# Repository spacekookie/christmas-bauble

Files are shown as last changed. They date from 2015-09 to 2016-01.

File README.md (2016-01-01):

# Kookies Christmas Bauble
A jolly christmas decoration on a PCB. Hoo hoo hoo!

It uses a 555 timer and a shift register + two buttons to generate patterns that are then displayed on a ring of simple LED's on the outside. The perfect thing to hang off your christmas tree in the jolly season (I know I'm early...) :)

The design uses SMD components (except for the LED's that are throughhole). The original schematic and layout was done by Ashley Mills (https://github.com/staropram). **The board requires only one layer**! It can thus be made at home (if the apropriate tools for cutting the PCB are present).

Check out my blog article [here](http://spacekookie.de/hardware/jolly-christmas-decoration/) for details :)
The christmas bauble went into production on 17.11.2015. Unfortunately Revision 3.1 got produced, not the updated and much cooler Rev 3.2** :/ Check out the picture belo.wspi

**All the revision 3 boards up to and including Rev 3.2 have a flaw where the XOR gate (U1) will make the functionality useless!**
Do not solder it on. You have to bridge two pins to make it work. Revision 3.3 fixes the issue.

## Pictures

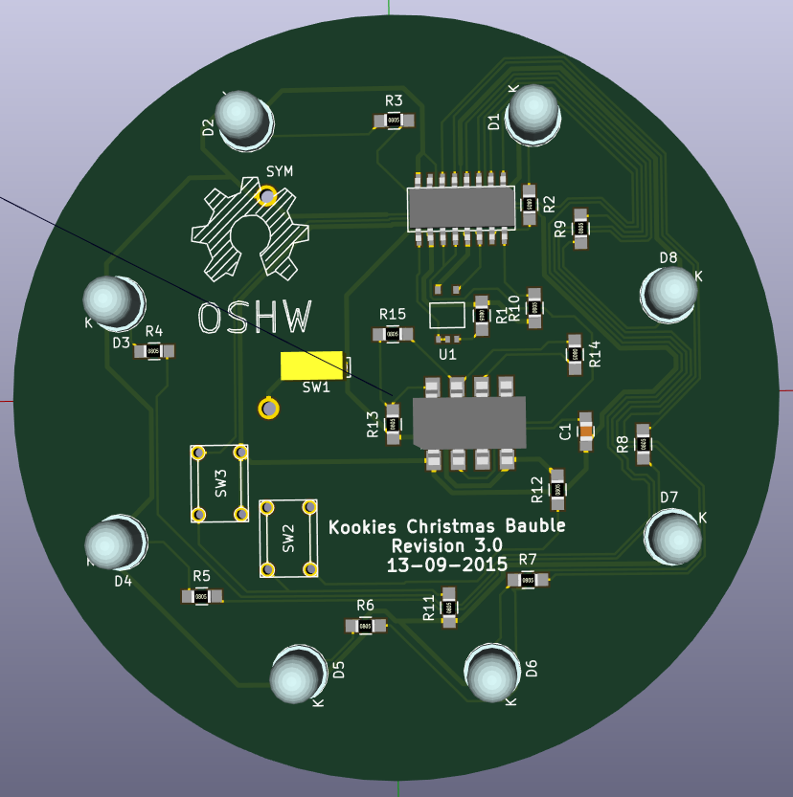
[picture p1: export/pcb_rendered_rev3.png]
PCB Rendered


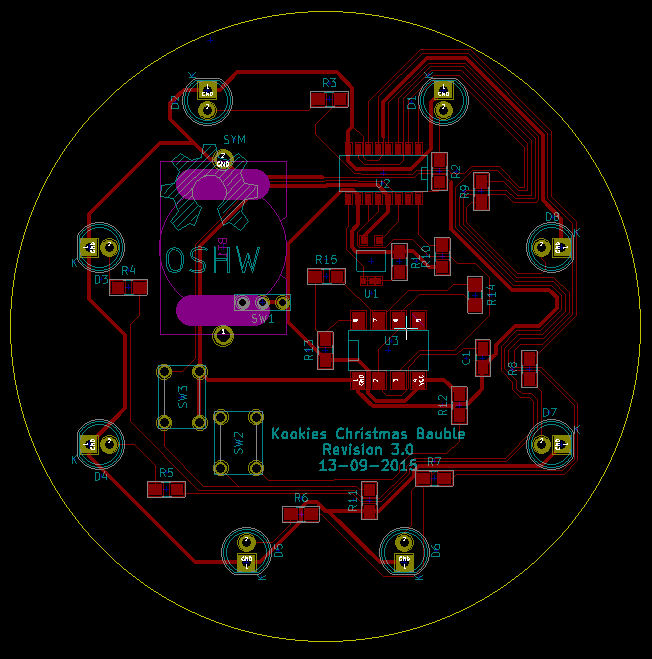
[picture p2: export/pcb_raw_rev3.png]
PCB Raw


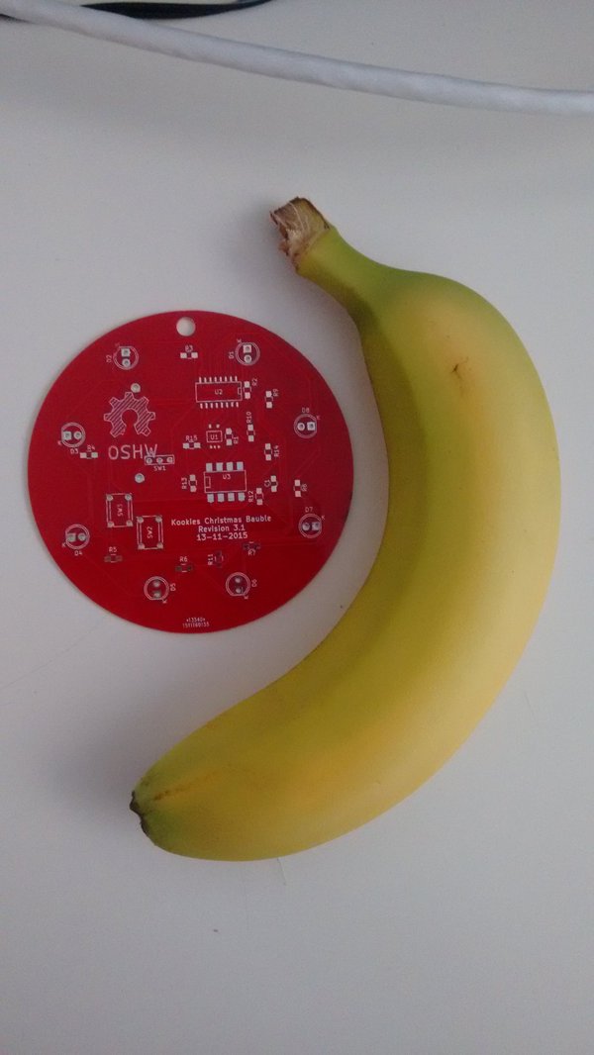
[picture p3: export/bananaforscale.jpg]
PCB Banana For Scale Banana for Scale!


## Partlist

Battery Holder: http://www.mouser.de/ProductDetail/Keystone-Electronics/3012TR/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

Resistors: http://www.mouser.de/Passive-Components/Resistors/SMD-Resistors-Chip-Resistors/_/N-7h7yu?P=1yzmno7Z1yzmotu

595 Shift register: http://www.mouser.de/ProductDetail/Texas-Instruments/SN74HC165DR/?qs=sGAEpiMZZMtYFXwiBRPs00UWwMKcYyCs

555 Timer: http://www.mouser.de/ProductDetail/Texas-Instruments/TLC555CDR/?qs=sGAEpiMZZMuHTYi1bHPYELMHAyKcqQNZ

Capacitor: http://www.mouser.de/ProductDetail/Murata-Electronics/GRM32ER71E226KE15L/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 (you want 22 µF - Not sure if that's included in the Schematic and I'm too lazy to check right now)

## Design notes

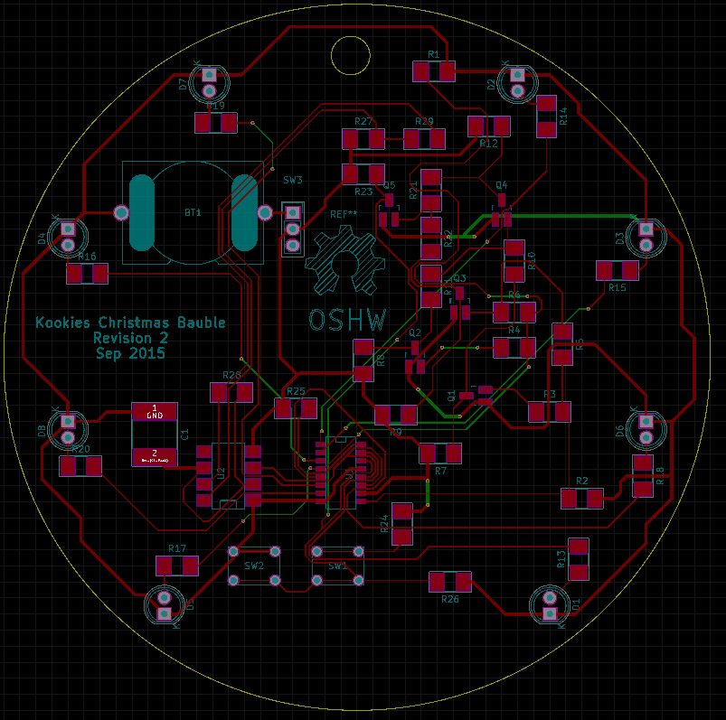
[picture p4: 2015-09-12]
export/pcb_raw.png

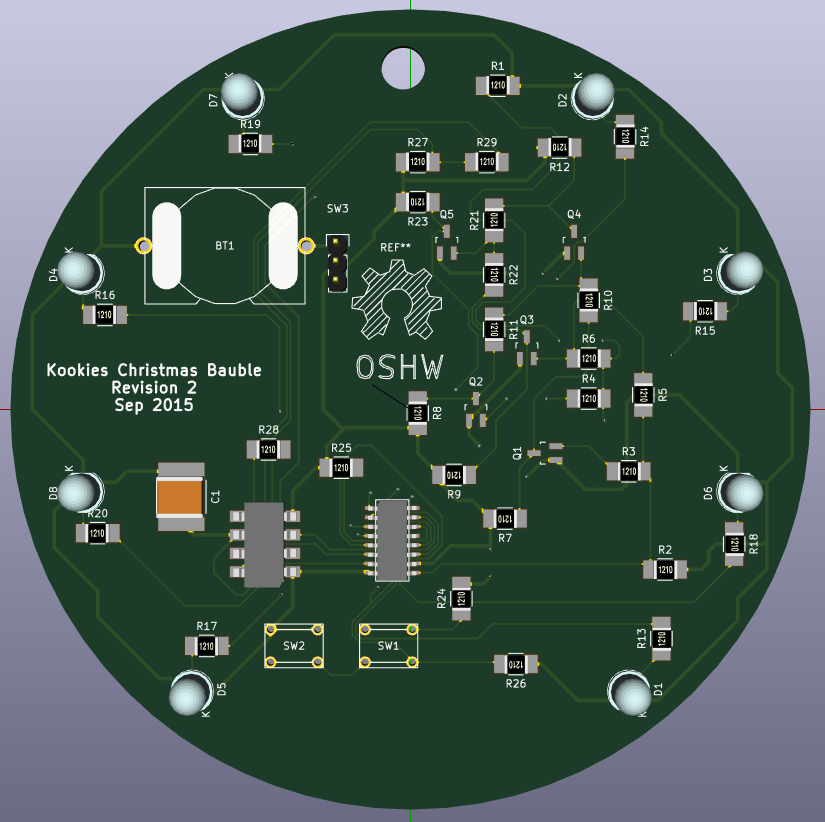
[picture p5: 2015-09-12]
export/pcb_rendered1.png

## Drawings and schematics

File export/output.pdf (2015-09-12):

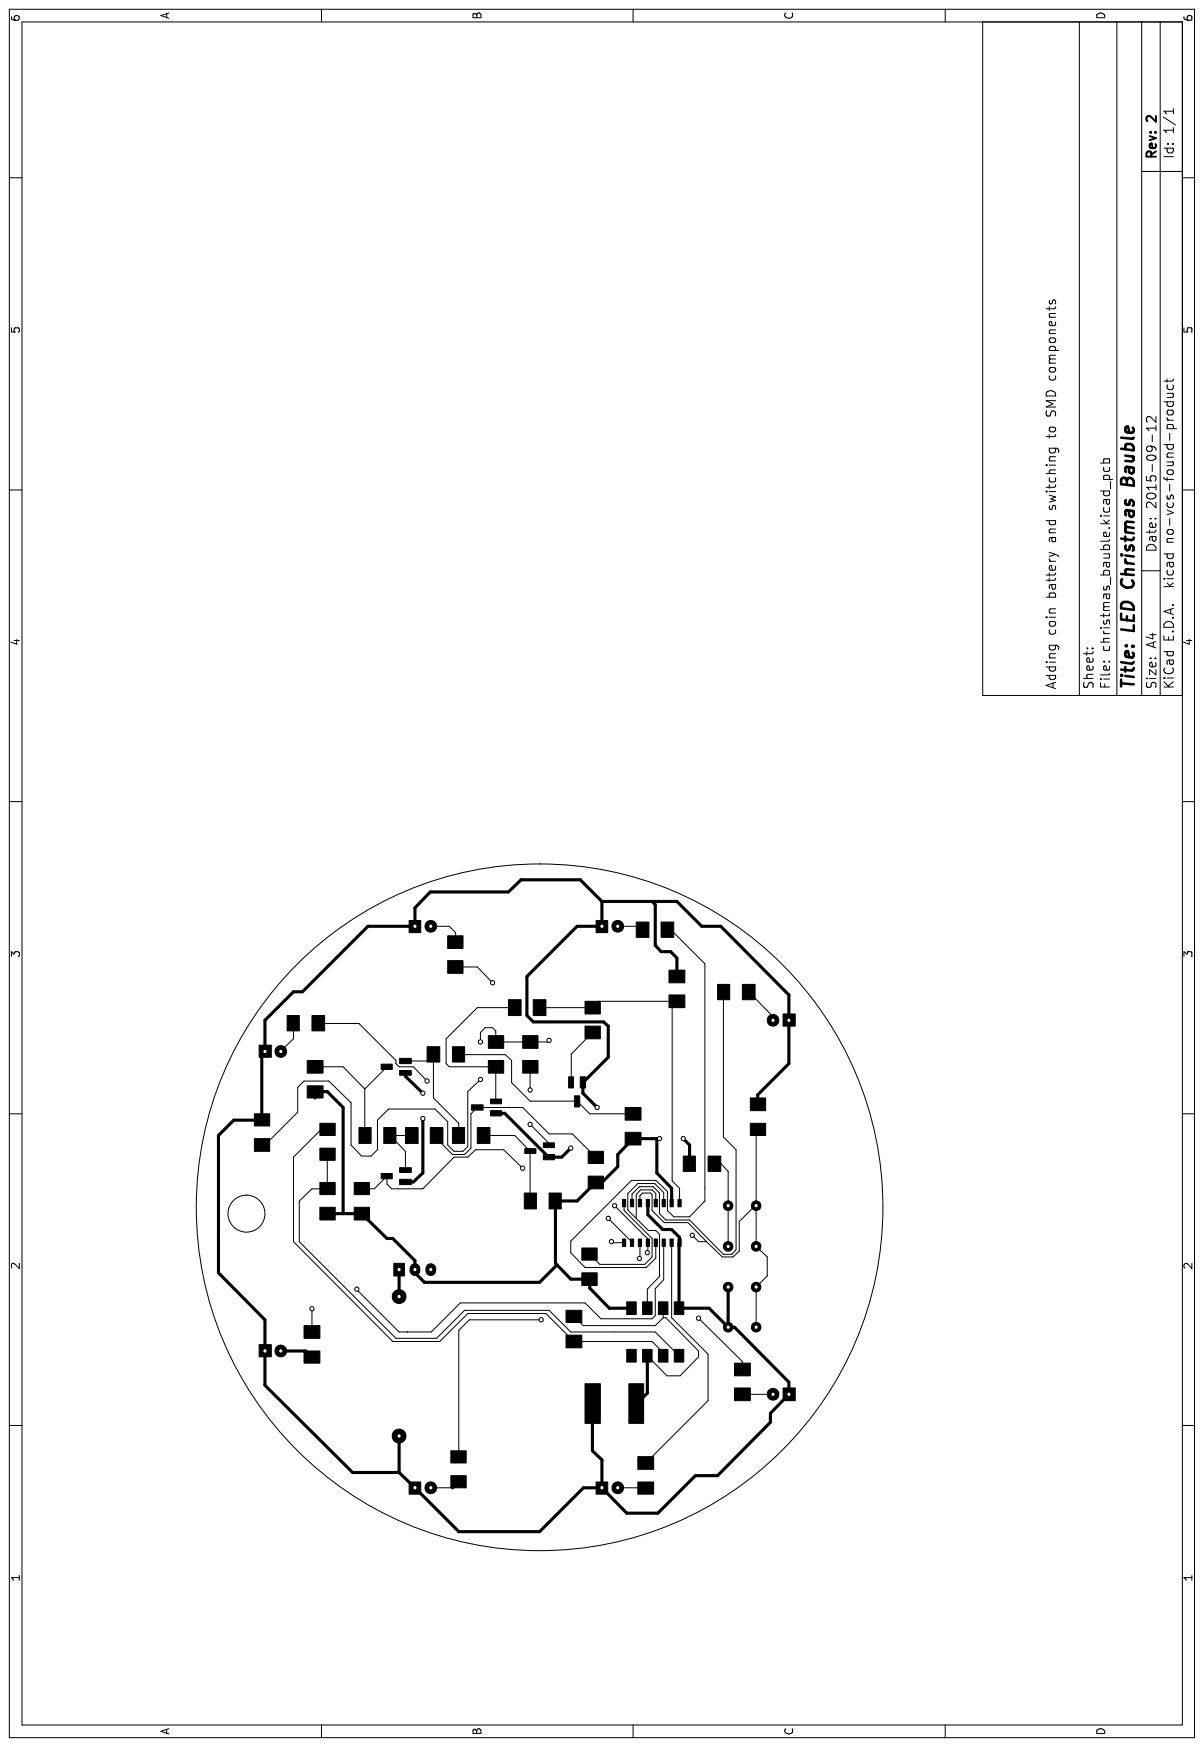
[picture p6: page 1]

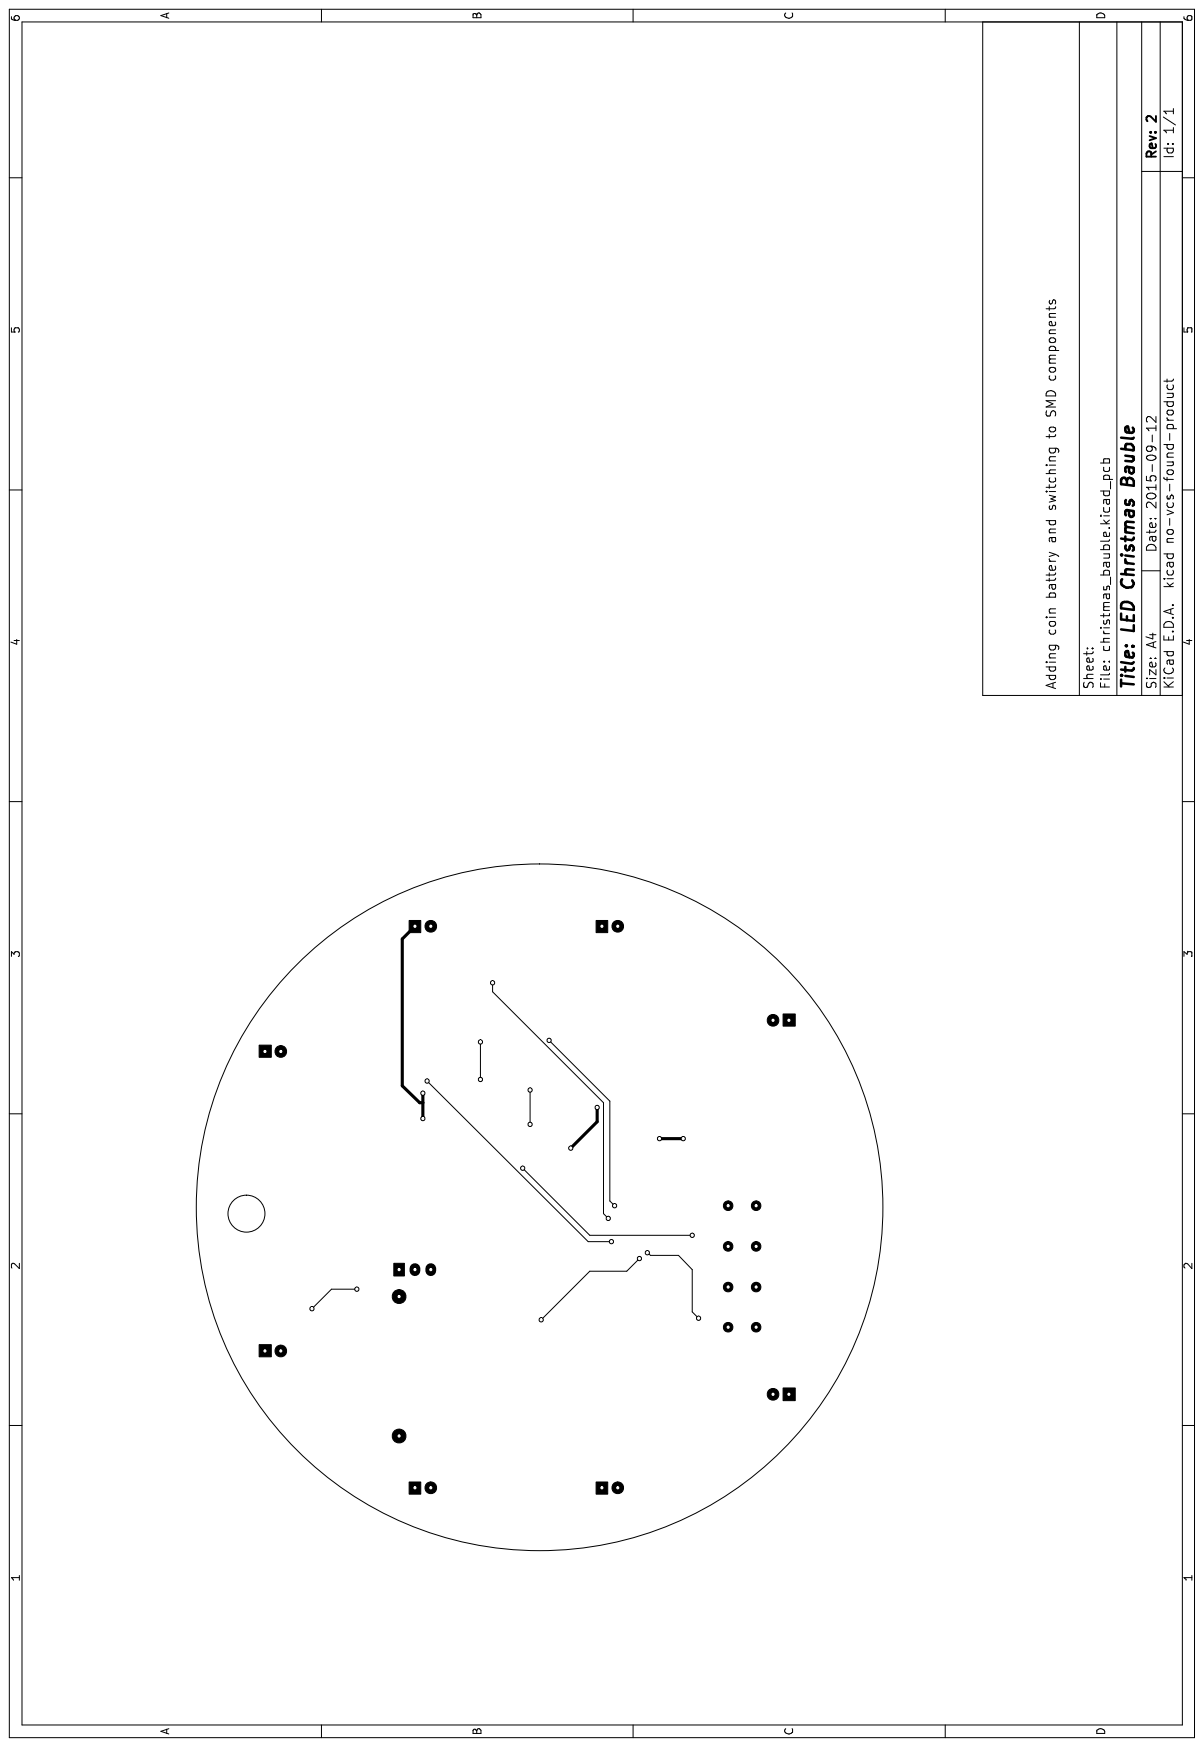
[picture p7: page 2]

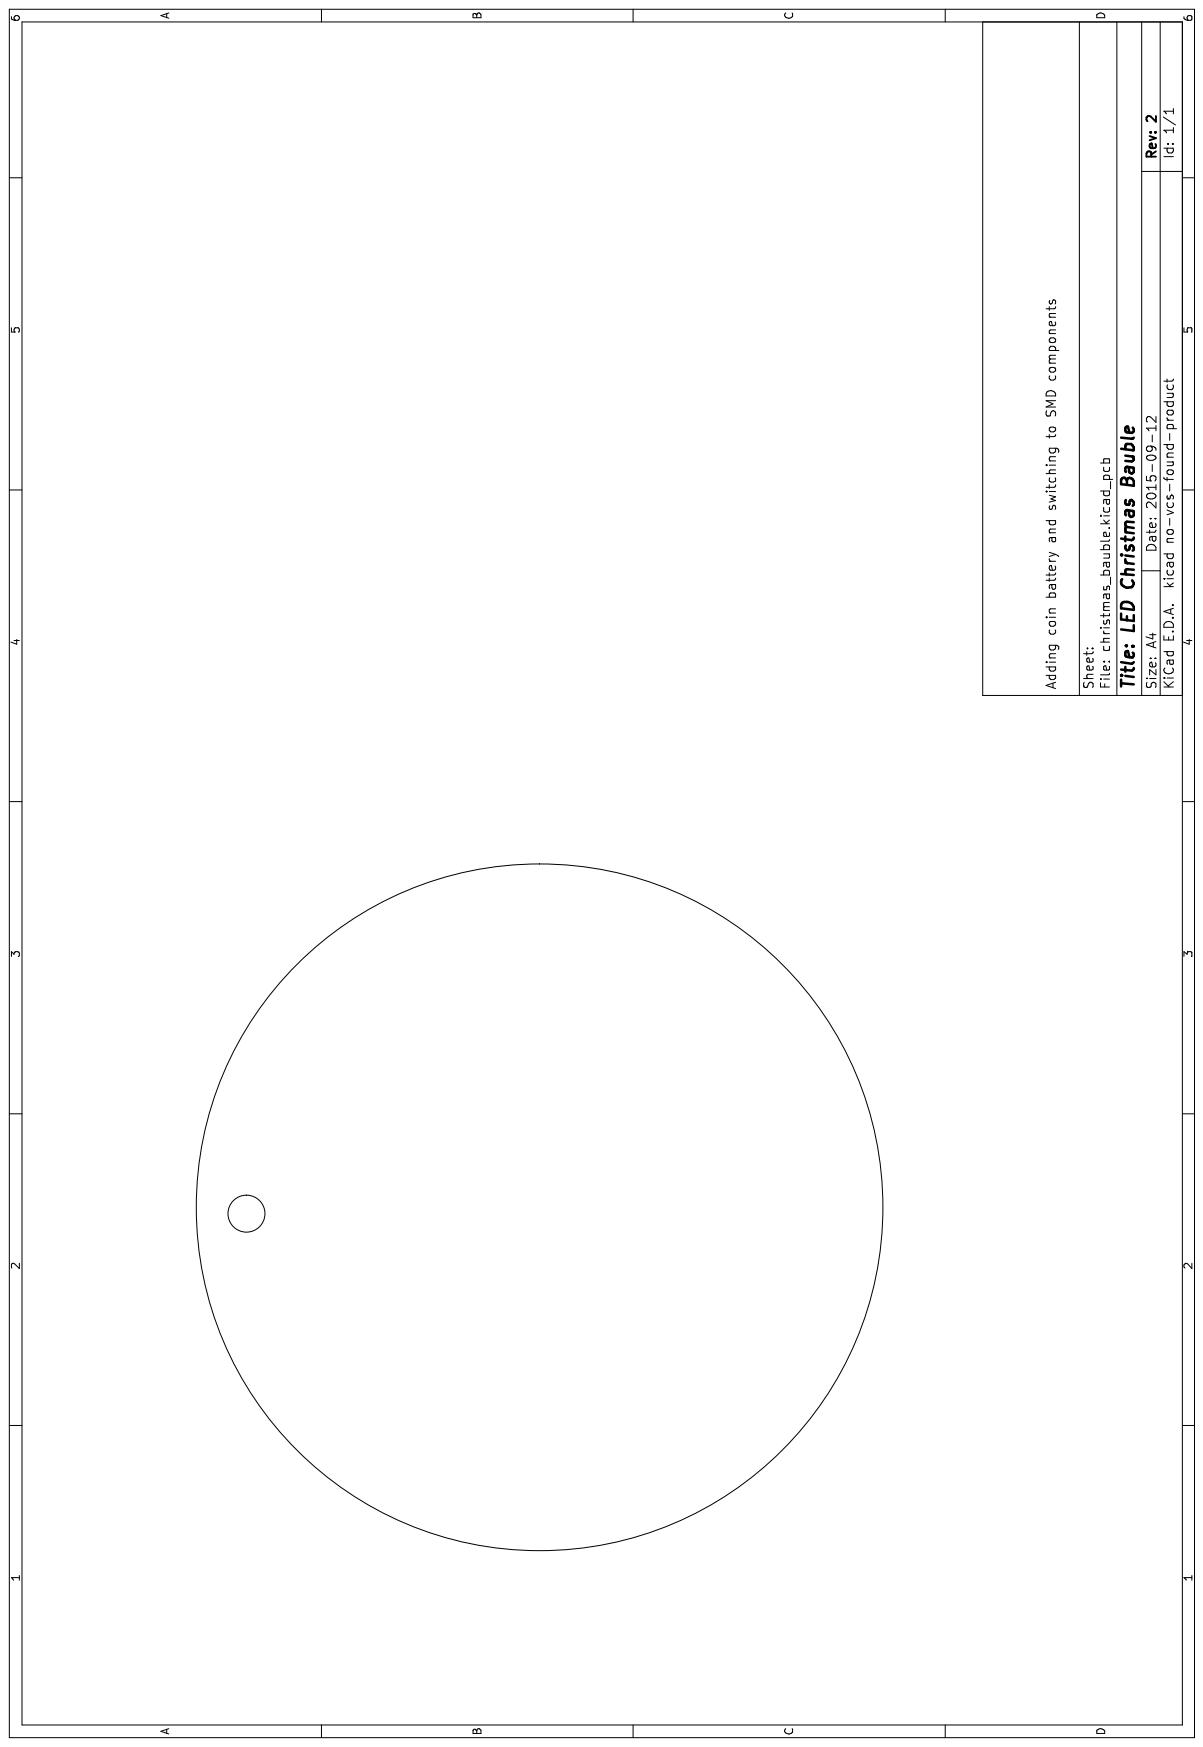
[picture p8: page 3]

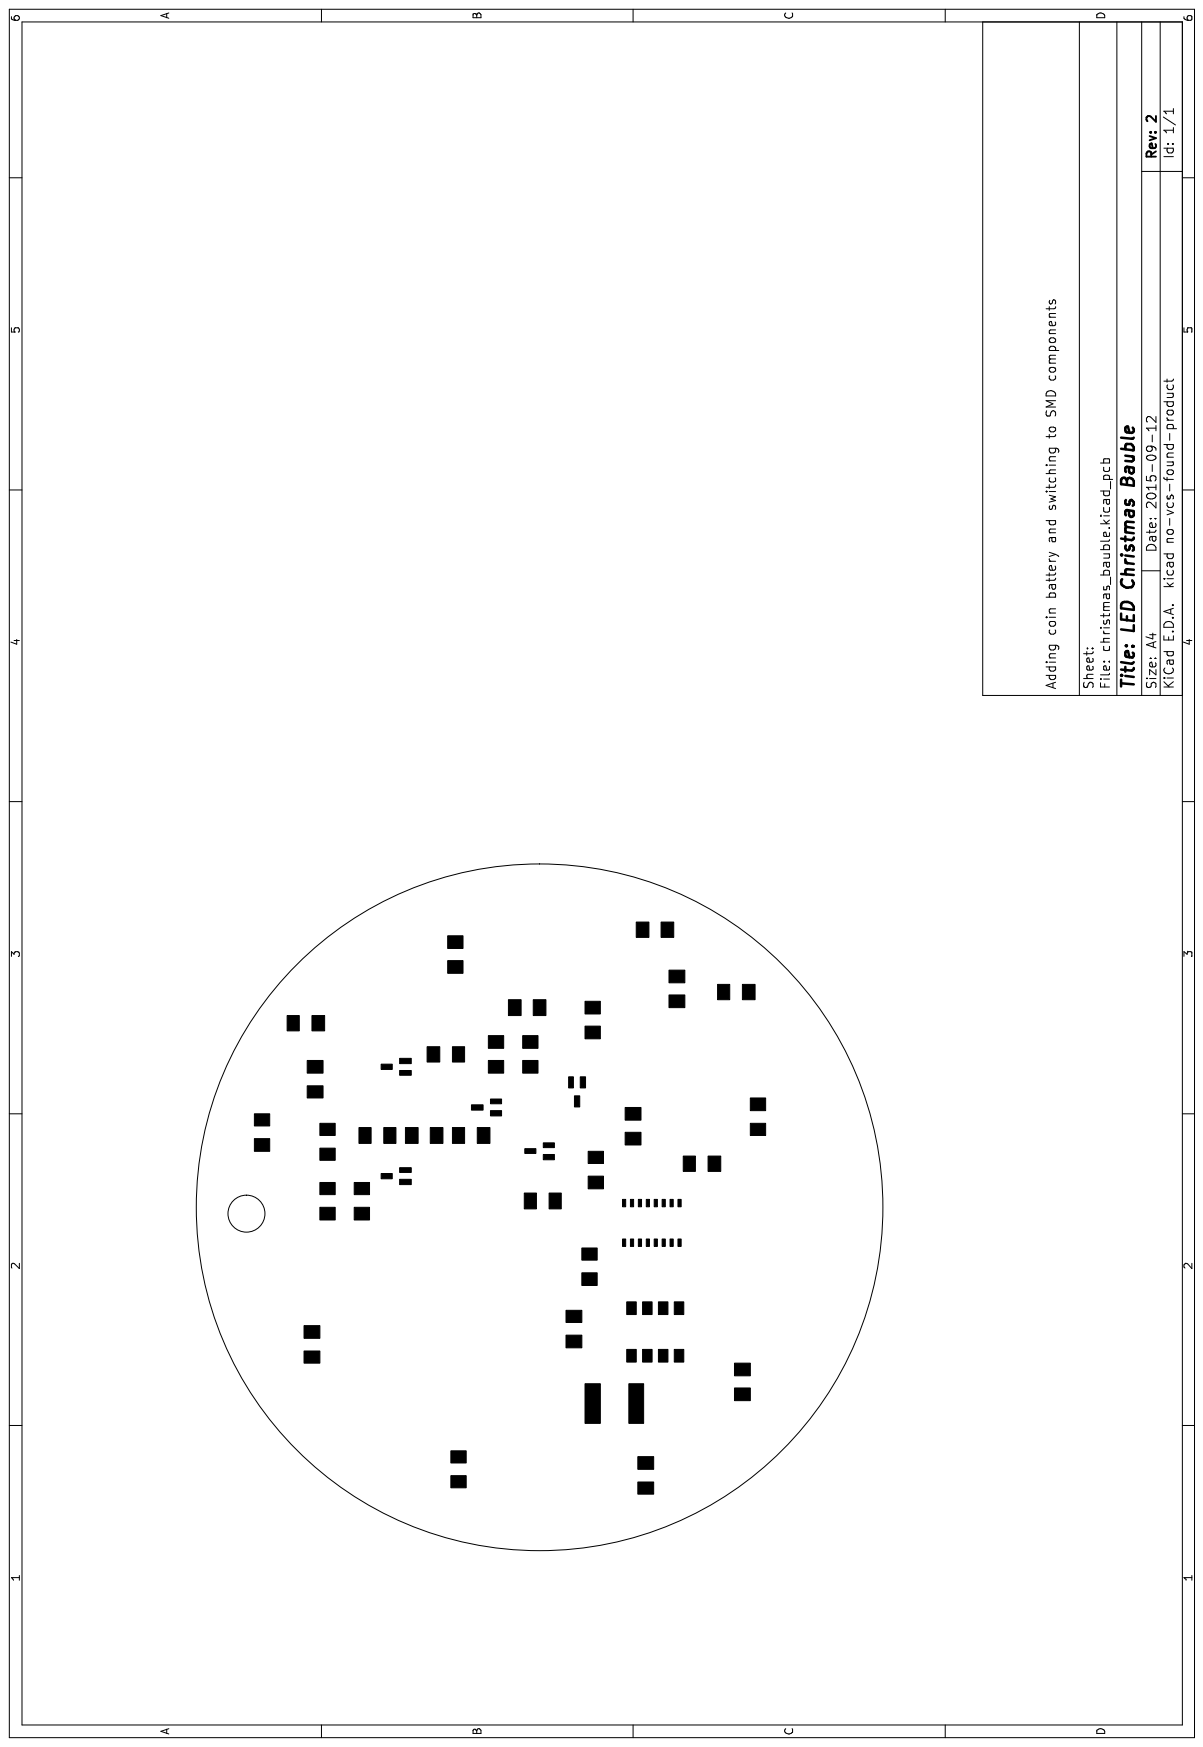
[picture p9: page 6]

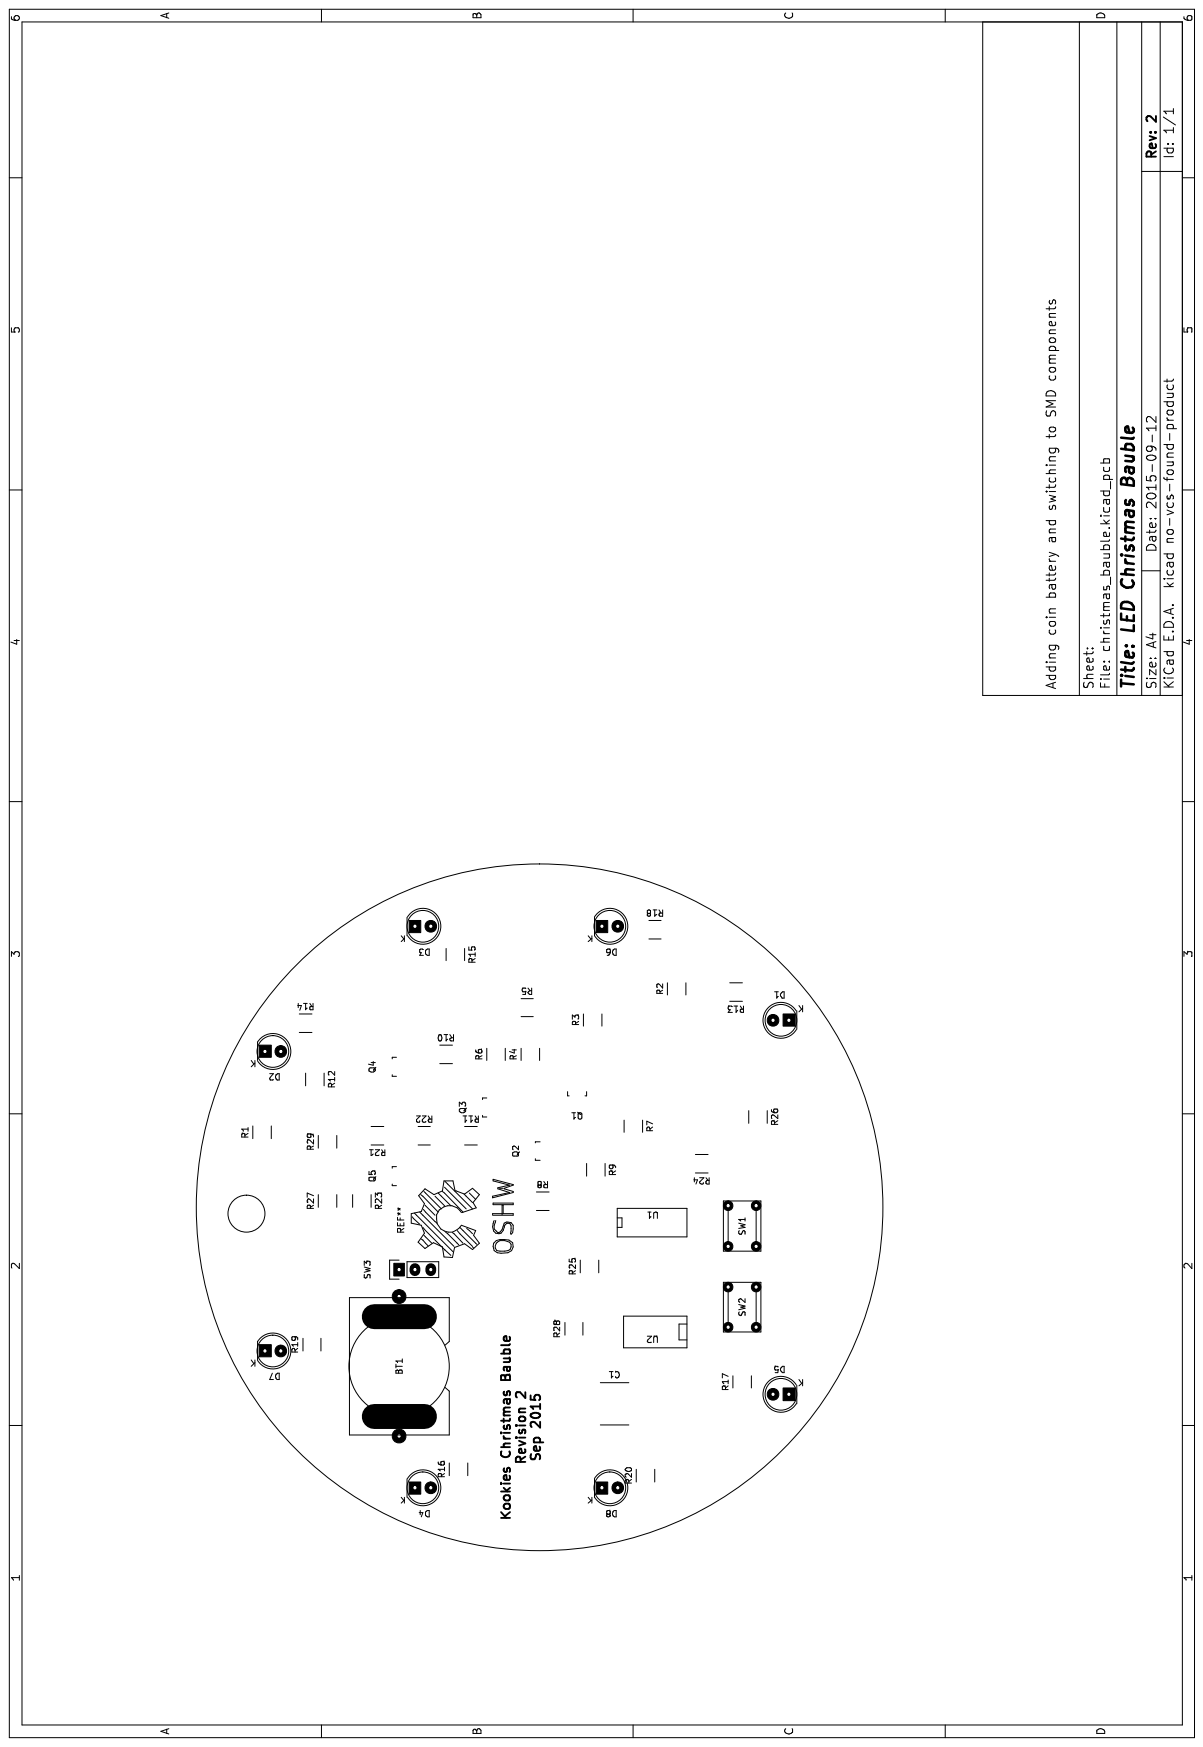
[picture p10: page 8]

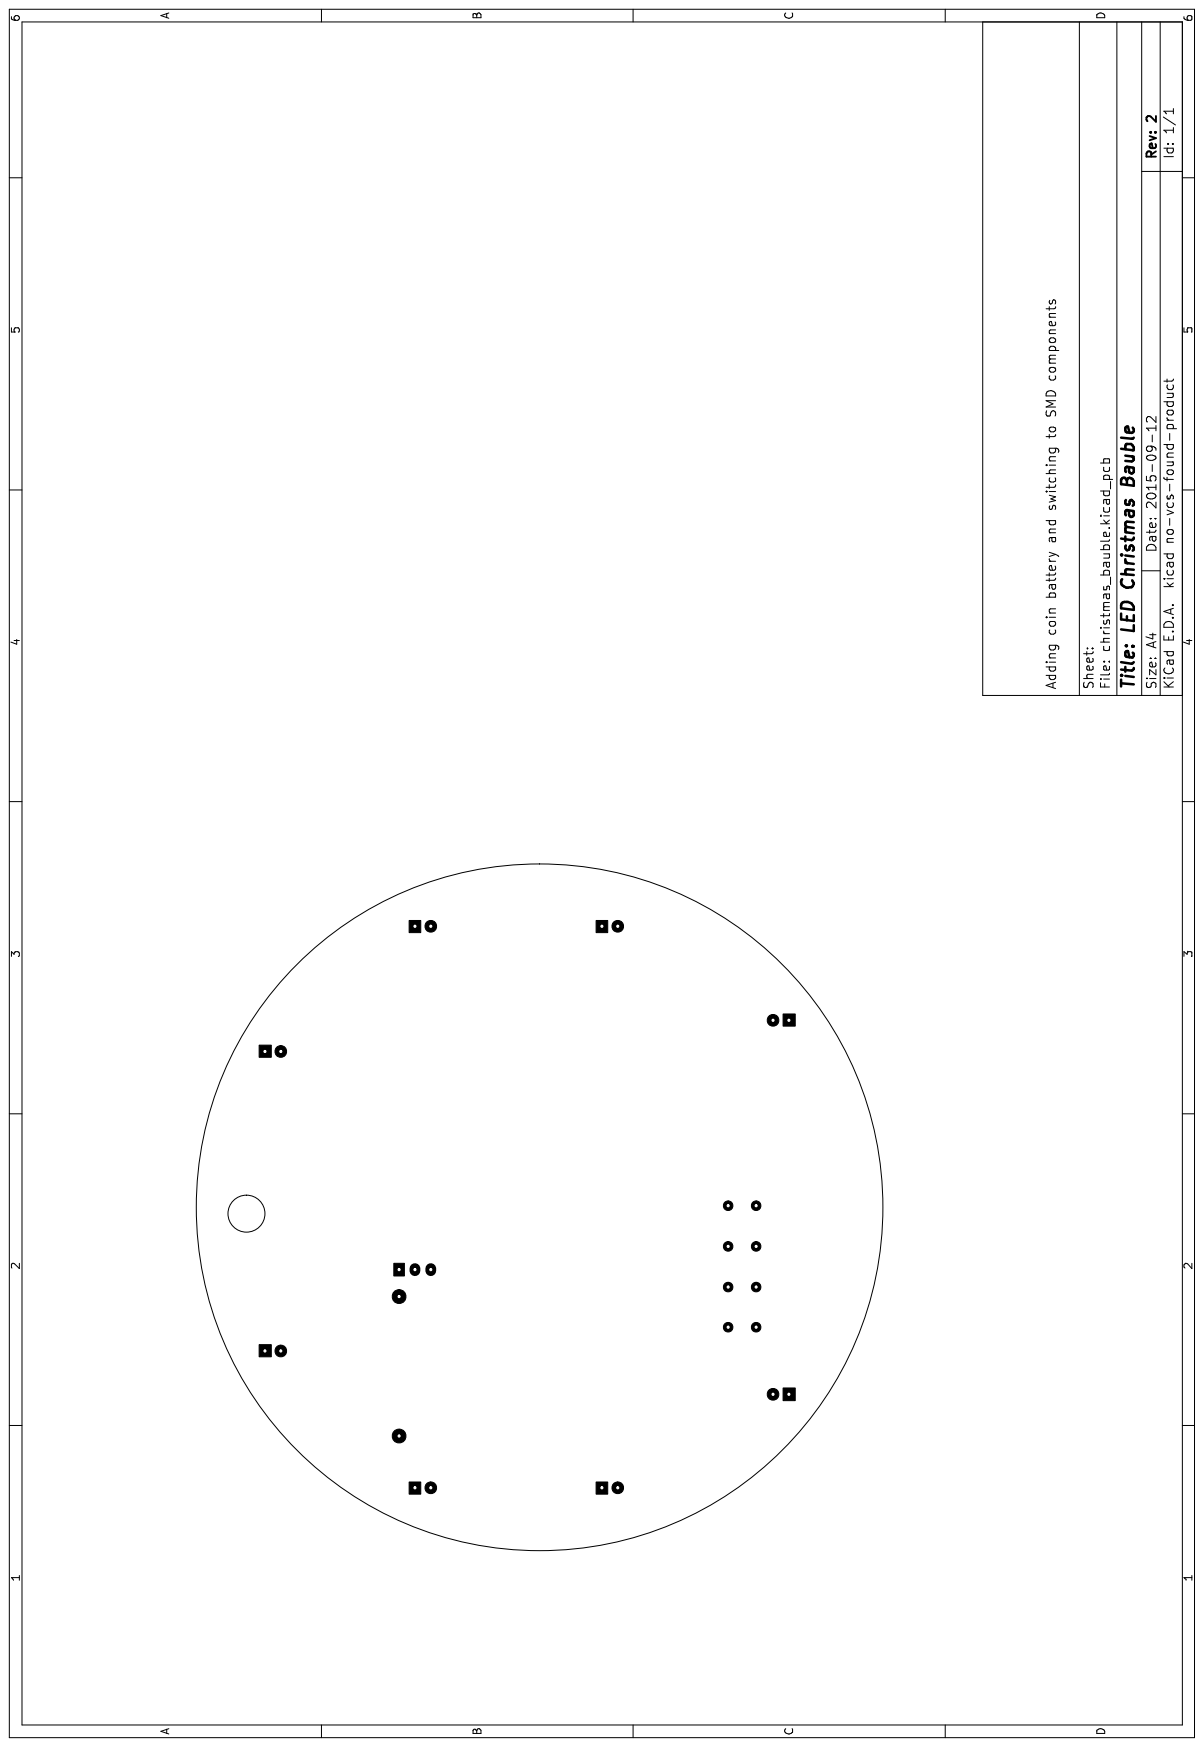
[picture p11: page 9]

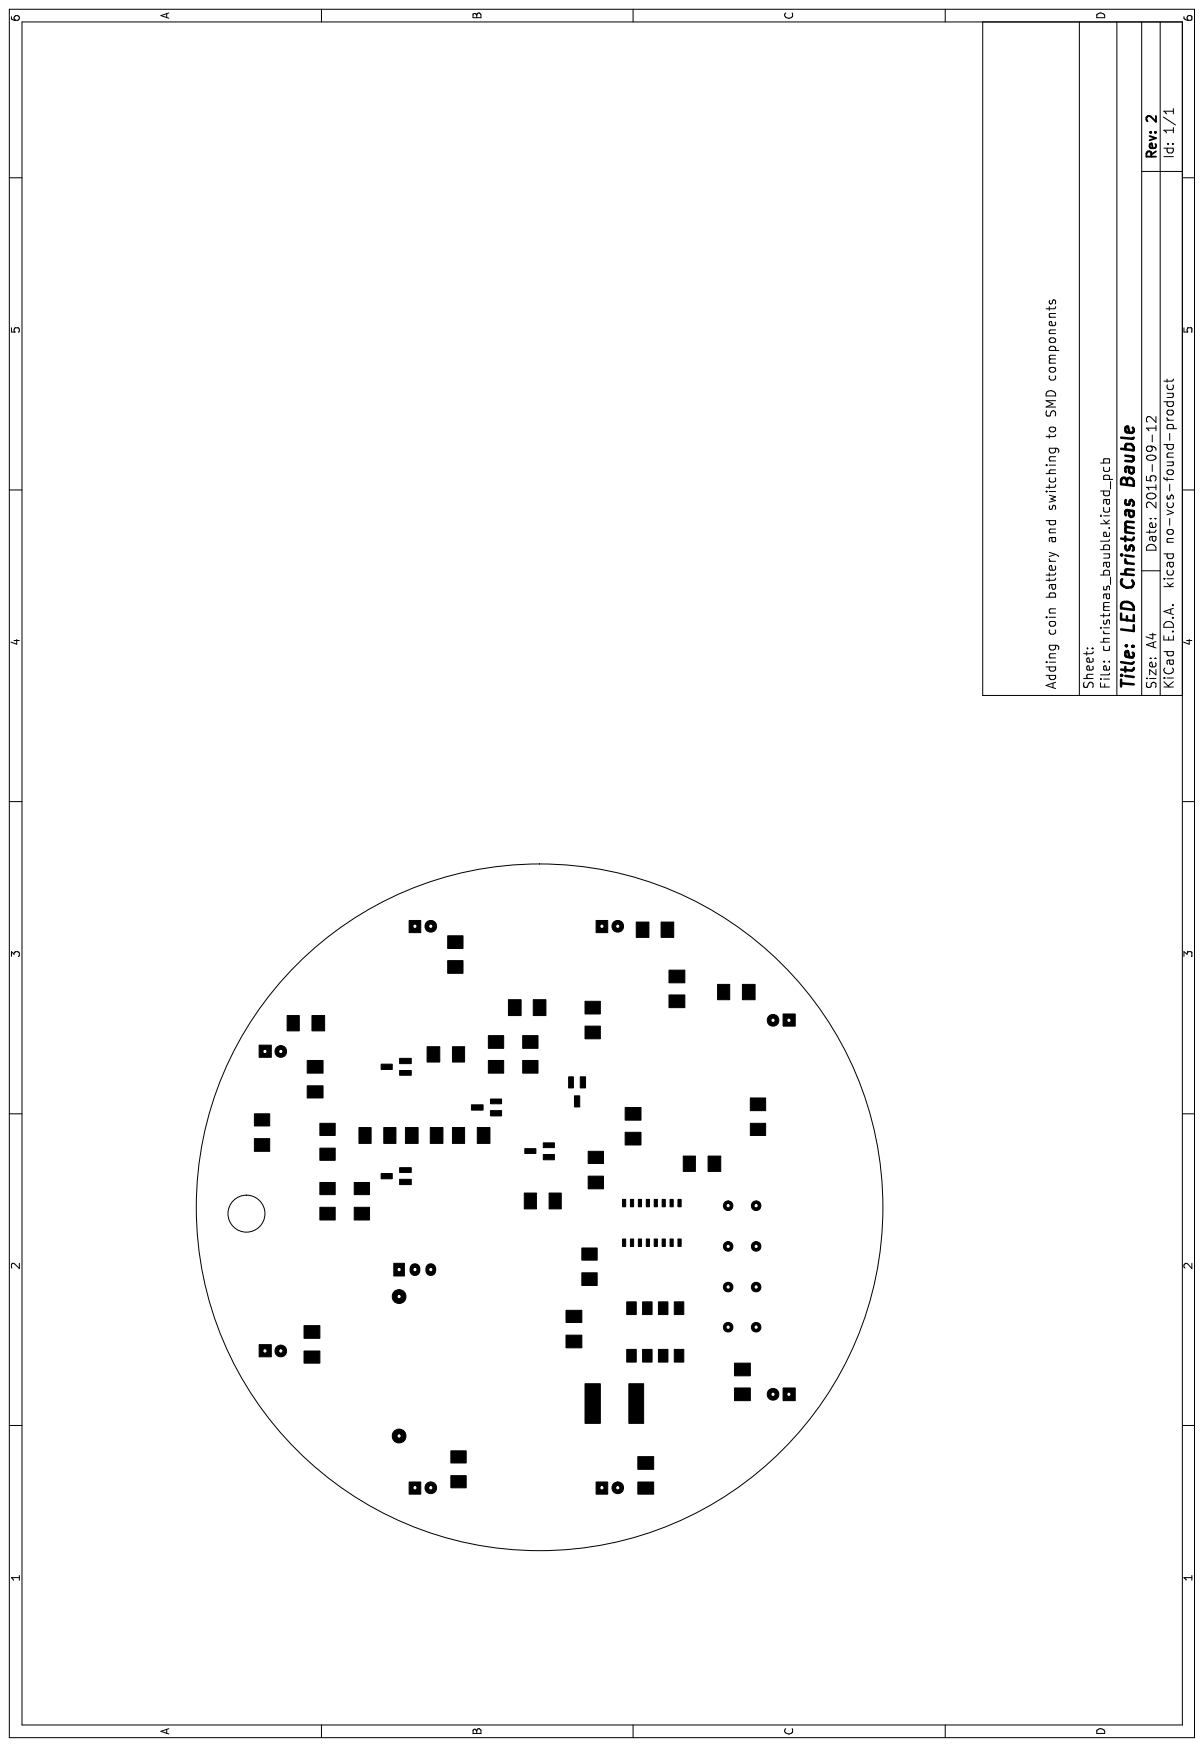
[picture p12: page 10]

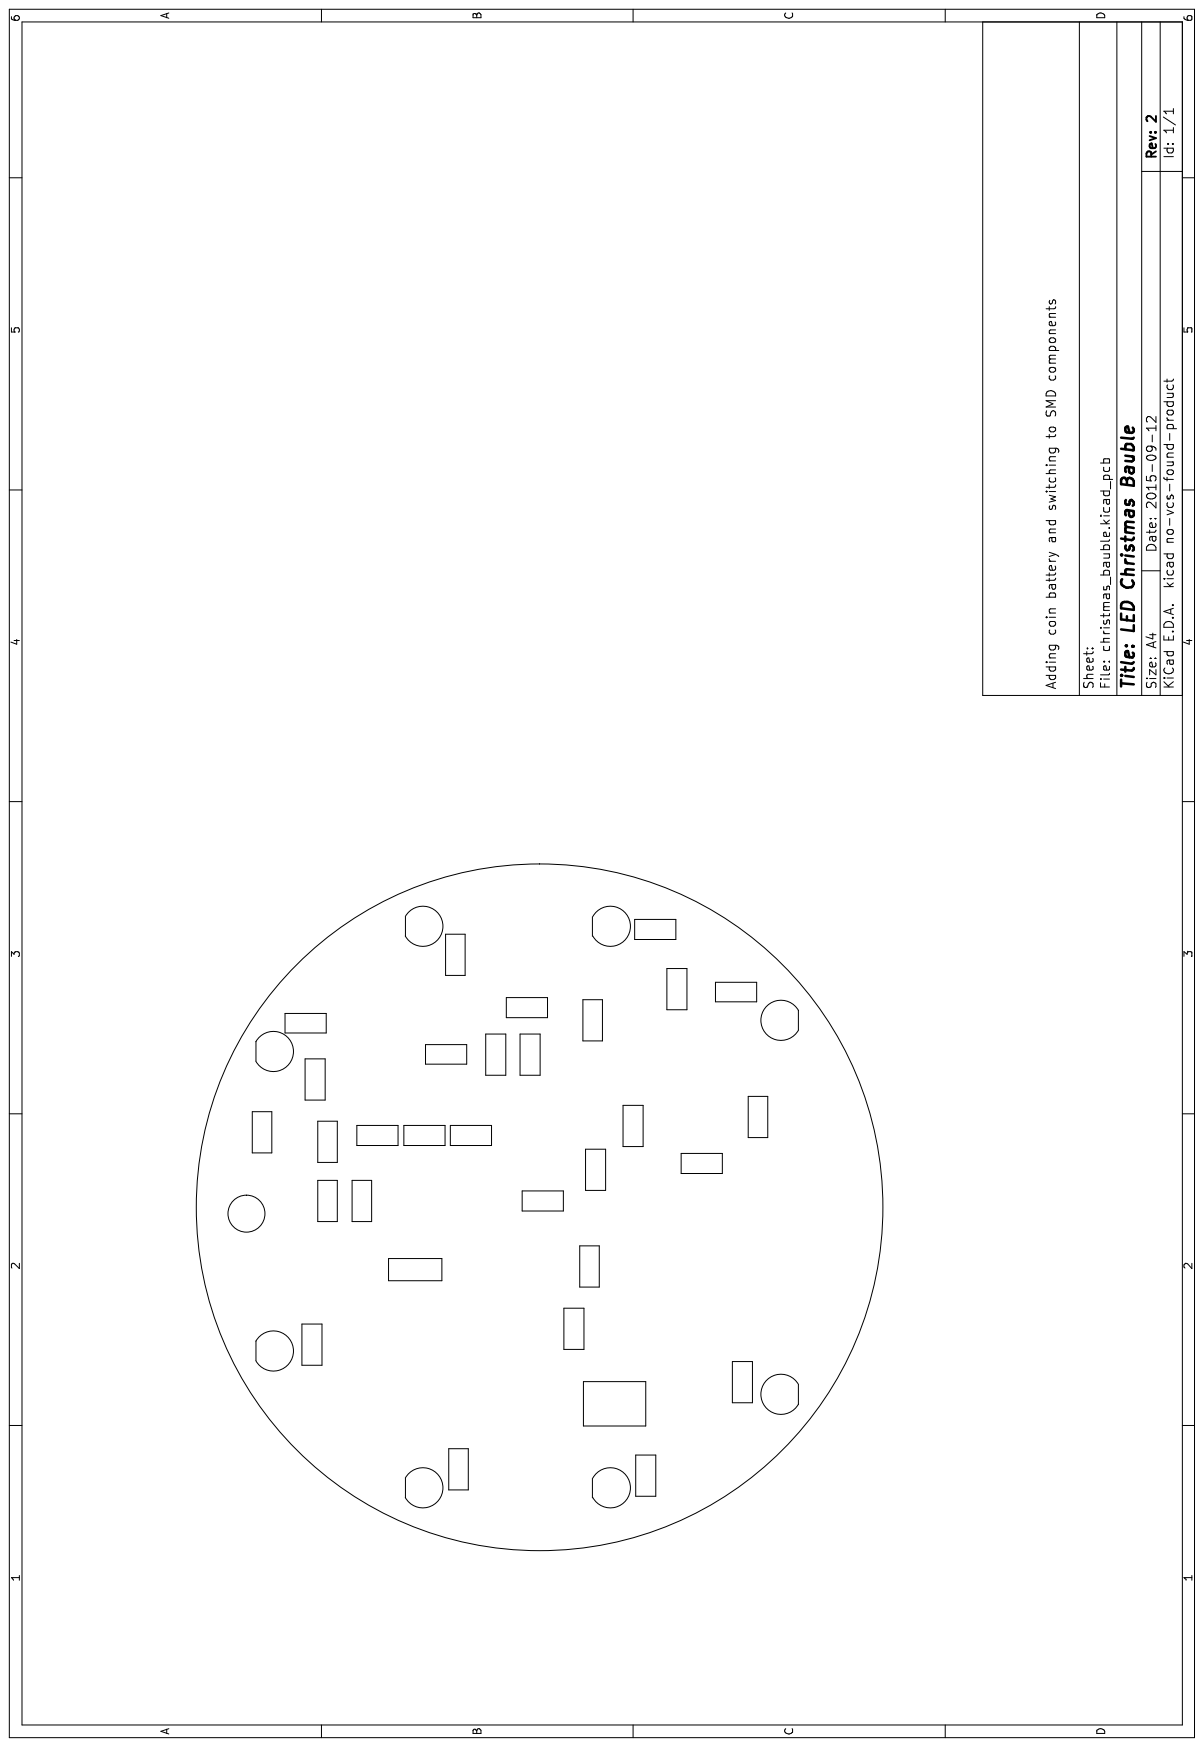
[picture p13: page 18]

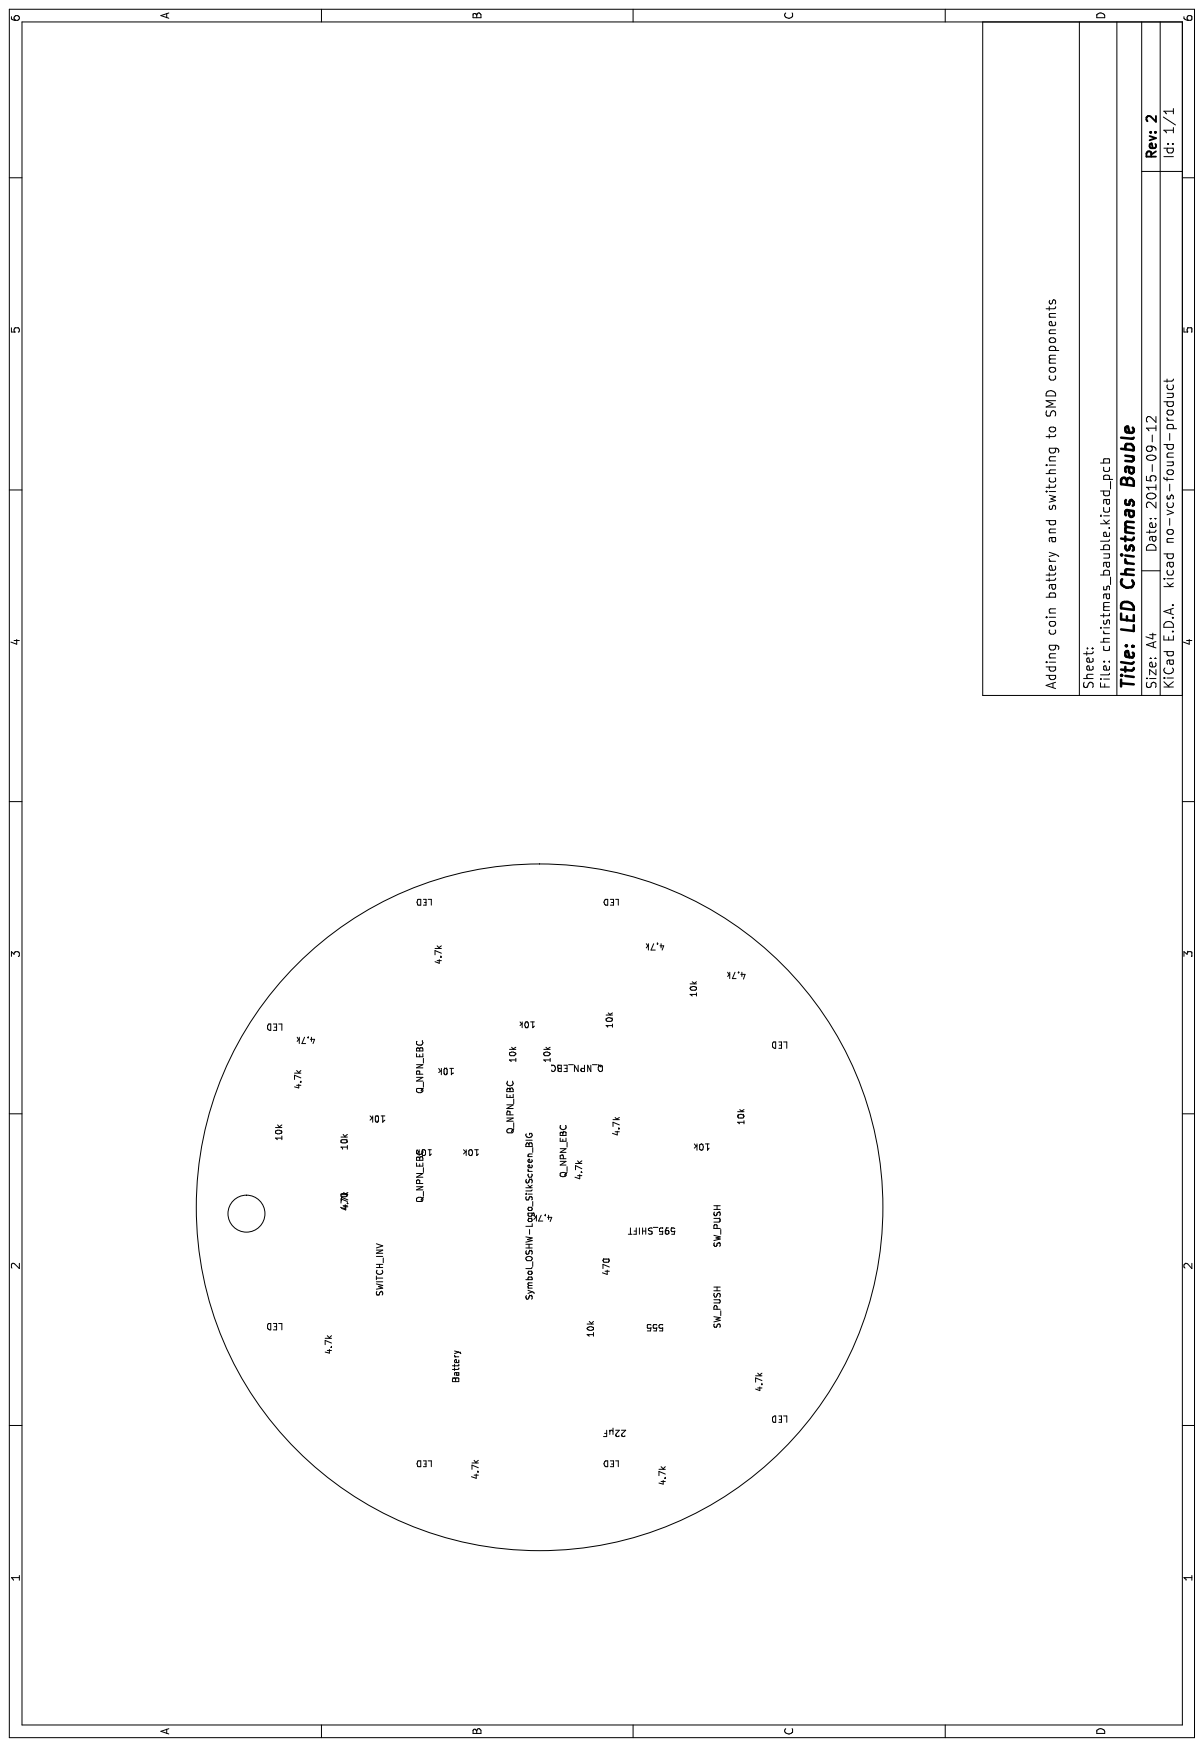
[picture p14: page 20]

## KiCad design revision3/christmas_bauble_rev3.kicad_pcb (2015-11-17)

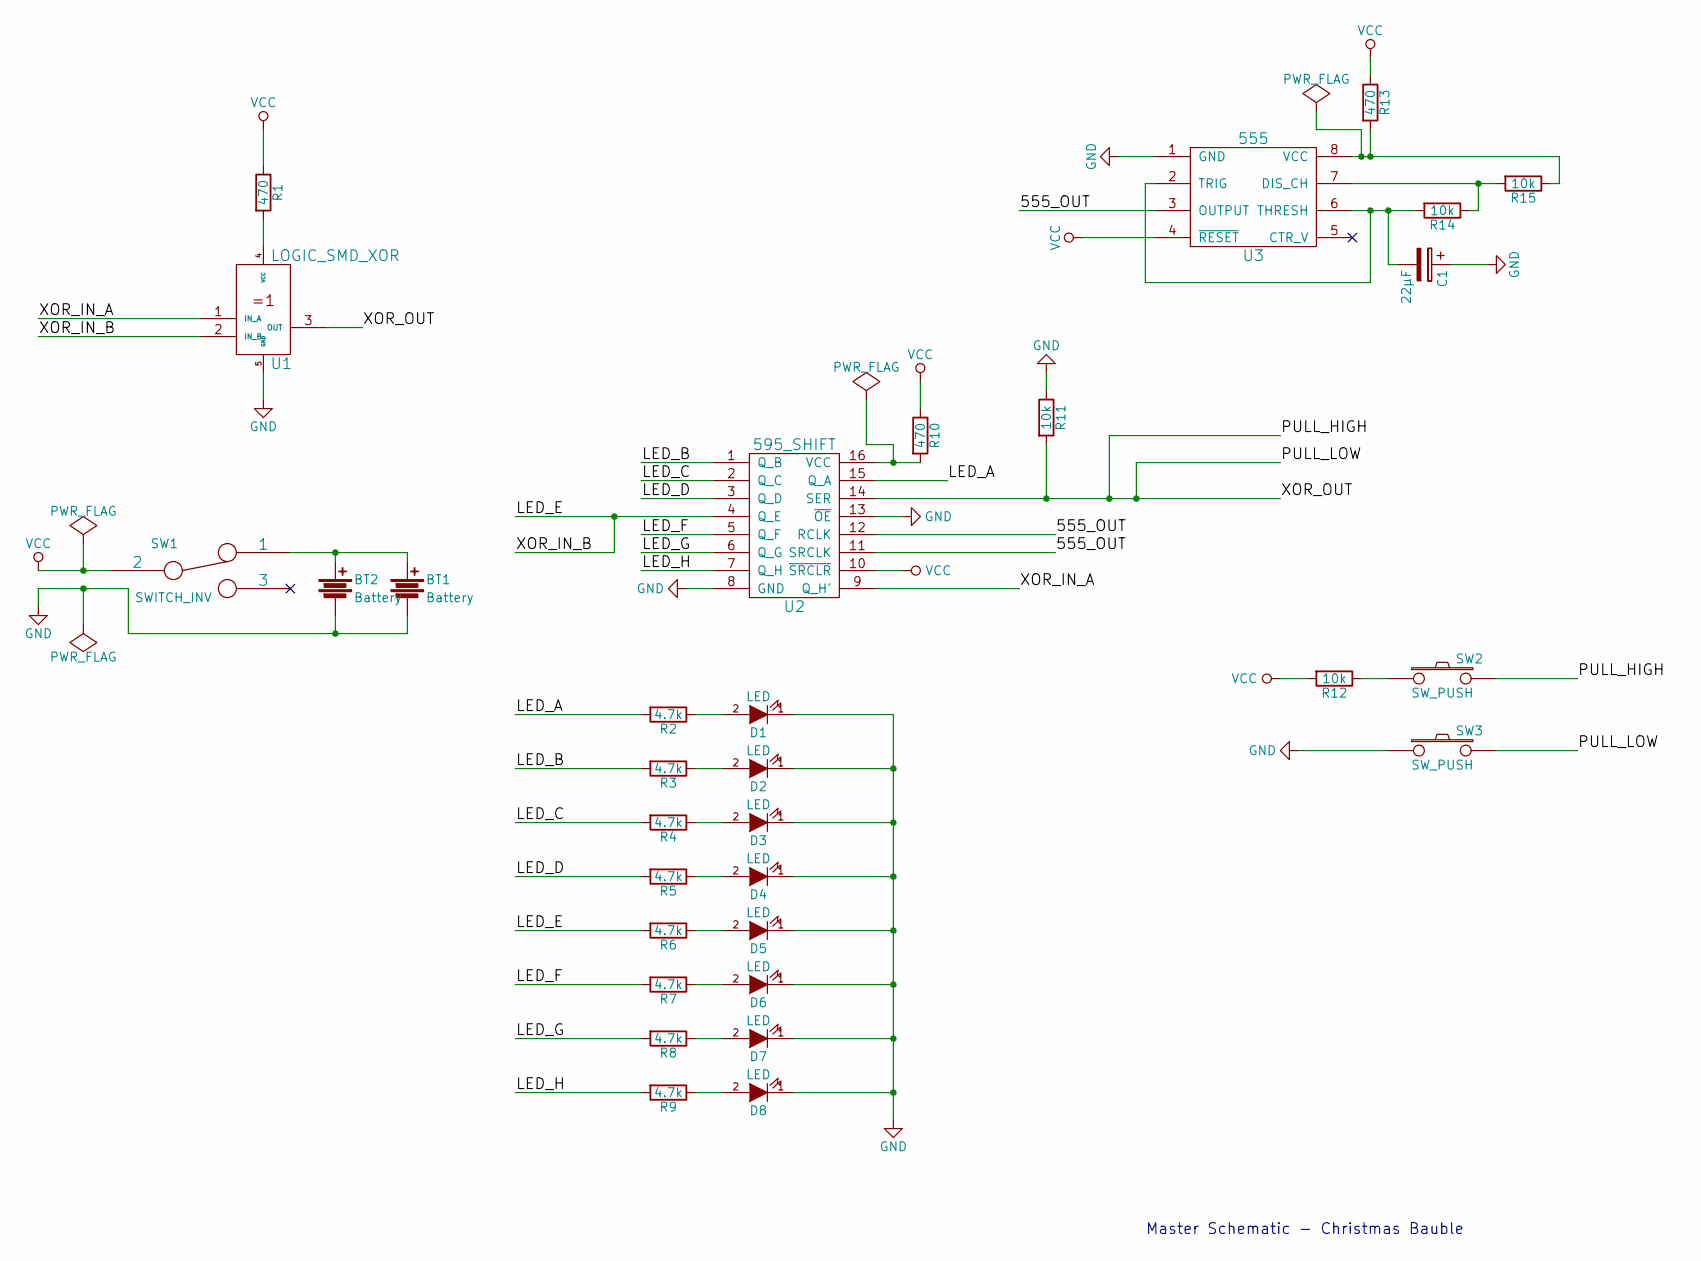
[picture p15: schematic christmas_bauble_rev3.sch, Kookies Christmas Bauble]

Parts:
BT1, BT2: Battery; 20mm_coin_bat_smd
C1: 22µF; SMD-1206_Pol
D1, D2, D3, D4, D5, D6, D7, D8: LED; LED-5MM
R1, R10, R13: 470; R_0805_HandSoldering
R2, R3, R4, R5, R6, R7, R8, R9: 4.7k; R_0805_HandSoldering
R11, R12, R14, R15: 10k; R_0805_HandSoldering
SW1: SWITCH_INV; C1-1
SW2, SW3: SW_PUSH; SW_TACTILE_SHALLOW
U1: LOGIC_SMD_XOR; LOGIC_SMD_5PIN_SOT-23-5
U2: 595_SHIFT; SO-16-N
U3: 555; DIP-8_SMD

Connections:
/555_OUT: U2.11 (SRCLK), U2.12 (RCLK), U3.3 (OUTPUT)
/LED_A: R2.2, U2.15 (Q_A)
/LED_B: R3.2, U2.1 (Q_B)
/LED_C: R4.2, U2.2 (Q_C)
/LED_D: R5.2, U2.3 (Q_D)
/LED_E: R6.2, U1.2 (IN_B), U2.4 (Q_E)
/LED_F: R7.2, U2.5 (Q_F)
/LED_G: R8.2, U2.6 (Q_G)
/LED_H: R9.2, U2.7 (Q_H)
/PULL_HIGH: R11.2, SW2.2, SW3.2, U1.3 (OUT), U2.14 (SER)
/XOR_IN_A: U1.1 (IN_A), U2.9 (Q_H')
GND: BT1.2, BT2.2, C1.1, D1.1 (K), D2.1 (K), D3.1 (K), D4.1 (K), D5.1 (K), D6.1 (K), D7.1 (K), D8.1 (K), R11.1, SW3.1, U1.5 (GND), U2.8 (GND), U2.13 (~OE), U3.1 (GND)
unnamed: BT1.1, BT2.1, SW1.1
unnamed: C1.2, R14.2, U3.2 (TRIG), U3.6 (THRESH)
unnamed: D1.2 (A), R2.1
unnamed: D2.2 (A), R3.1
unnamed: D3.2 (A), R4.1
unnamed: D4.2 (A), R5.1
unnamed: D5.2 (A), R6.1
unnamed: D6.2 (A), R7.1
unnamed: D7.2 (A), R8.1
unnamed: D8.2 (A), R9.1
unnamed: R1.2, U1.4 (VCC)
unnamed: R10.2, U2.16 (VCC)
unnamed: R12.1, SW2.1
unnamed: R13.2, R15.1, U3.8 (VCC)
unnamed: R14.1, R15.2, U3.7 (DIS_CH)
VCC: R1.1, R10.1, R12.2, R13.1, SW1.2, U2.10 (~SRCLR), U3.4 (~RESET)

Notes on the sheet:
Master Schematic - Christmas Bauble

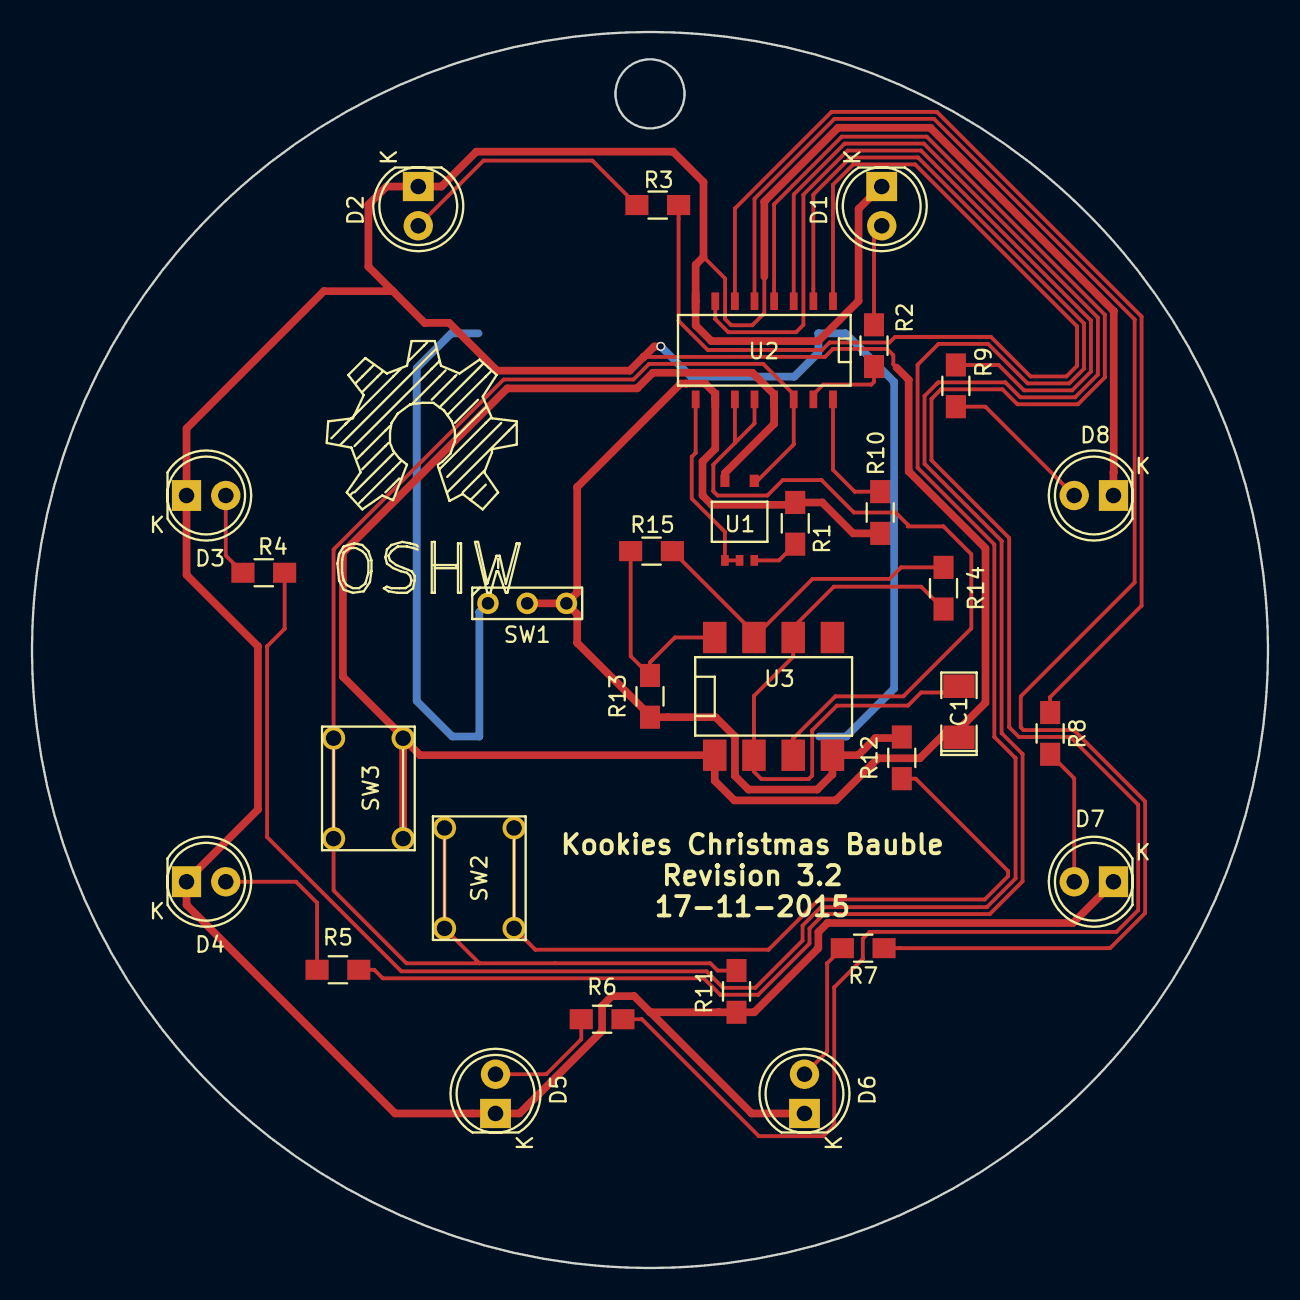
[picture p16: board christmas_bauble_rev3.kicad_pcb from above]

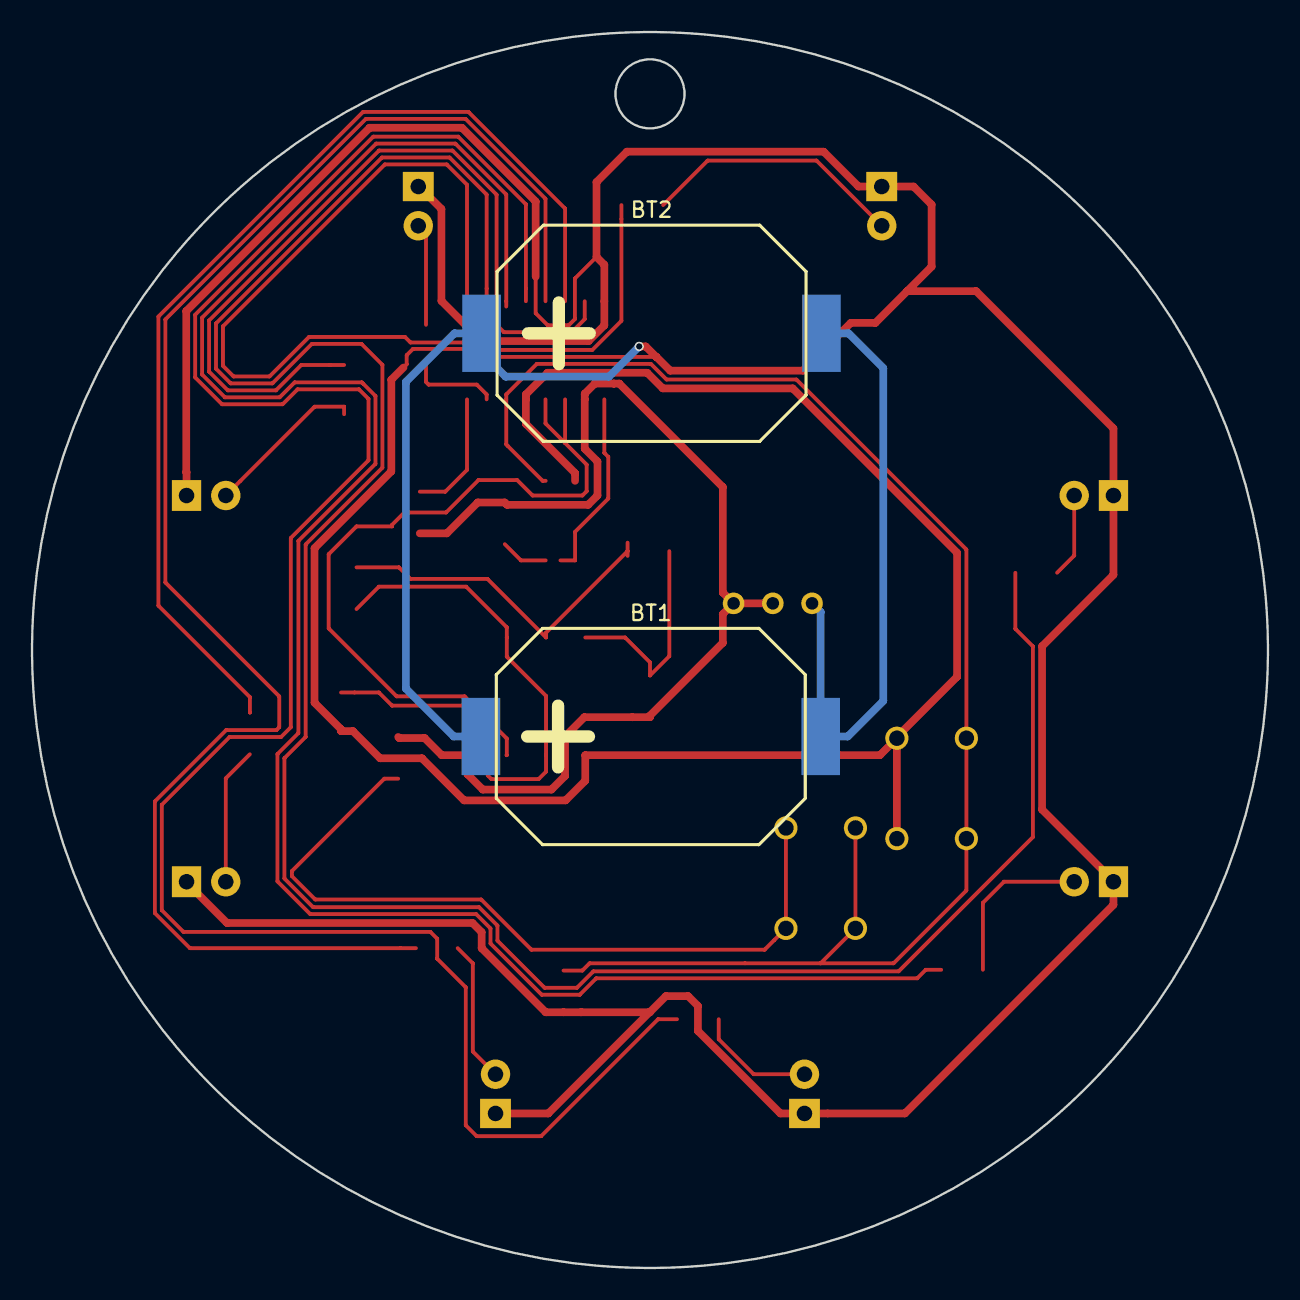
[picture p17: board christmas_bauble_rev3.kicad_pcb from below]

Board: 2 copper layers, 80.0 x 80.0 mm, 33 parts (2 on the bottom side), 28 nets.

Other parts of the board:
SYM: Symbol_OSHW-Logo_SilkScreen_BIG

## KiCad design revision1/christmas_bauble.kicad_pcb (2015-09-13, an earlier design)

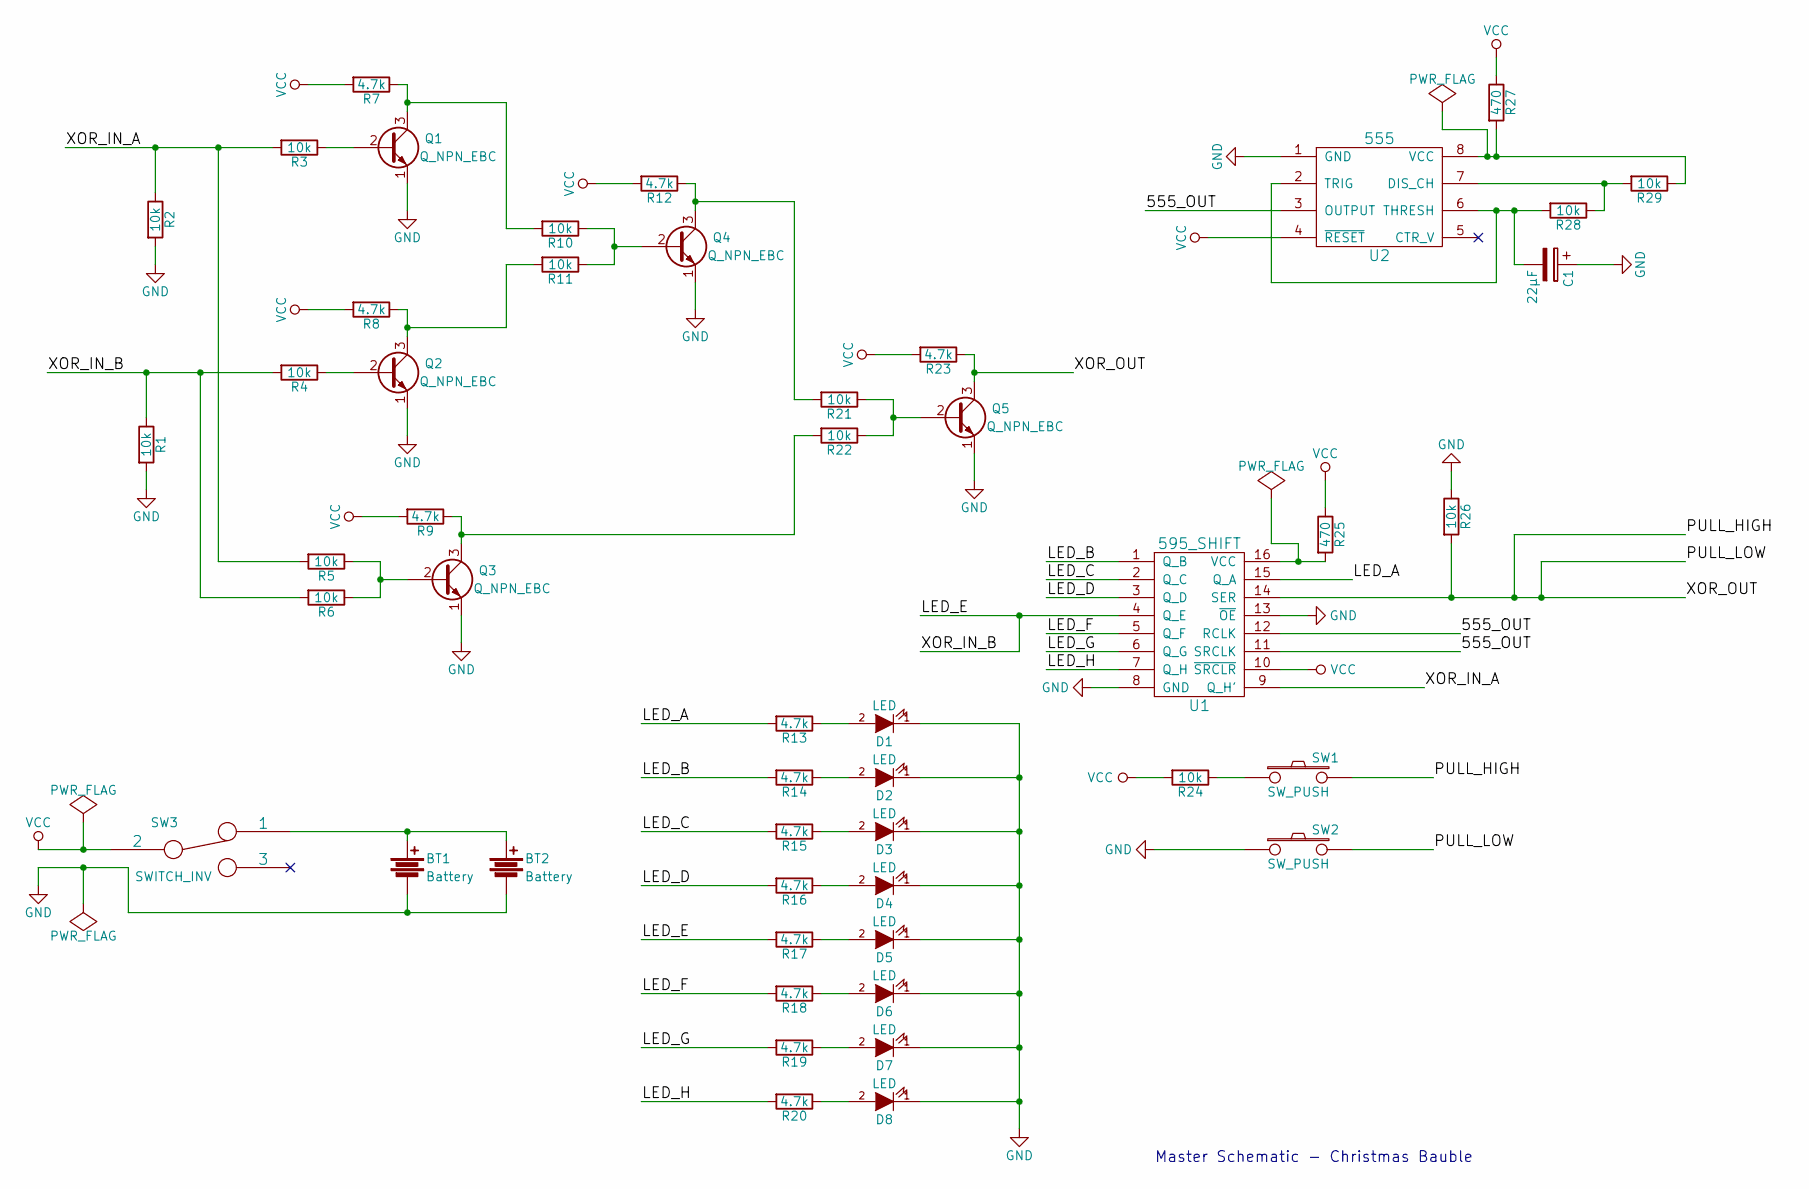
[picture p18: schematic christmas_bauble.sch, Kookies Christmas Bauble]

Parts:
BT1, BT2: Battery; 20mm_coin_bat_smd
C1: 22µF; C_2225_HandSoldering
D1, D2, D3, D4, D5, D6, D7, D8: LED; LED-5MM
Q1, Q2, Q3, Q4, Q5: Q_NPN_EBC; SOT-23_Handsoldering
R1, R2, R3, R4, R5, R6, R10, R11, R21, R22, R24, R26, R28, R29: 10k; R_1210_HandSoldering
R7, R8, R9, R12, R13, R14, R15, R16, R17, R18, R19, R20, R23: 4.7k; R_1210_HandSoldering
R25, R27: 470; R_1210_HandSoldering
SW1, SW2: SW_PUSH; SW_TACTILE_SHALLOW
SW3: SWITCH_INV; C1-1
U1: 595_SHIFT; SO-16-N
U2: 555; DIP-8_SMD

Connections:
/555_OUT: U1.11 (SRCLK), U1.12 (RCLK), U2.3 (OUTPUT)
/LED_A: R13.2, U1.15 (Q_A)
/LED_B: R14.2, U1.1 (Q_B)
/LED_C: R15.2, U1.2 (Q_C)
/LED_D: R16.2, U1.3 (Q_D)
/LED_E: R1.1, R4.2, R6.2, R17.2, U1.4 (Q_E)
/LED_F: R18.2, U1.5 (Q_F)
/LED_G: R19.2, U1.6 (Q_G)
/LED_H: R20.2, U1.7 (Q_H)
/PULL_HIGH: Q5.3 (C), R23.1, R26.2, SW1.2, SW2.2, U1.14 (SER)
/XOR_IN_A: R2.1, R3.2, R5.2, U1.9 (Q_H')
GND: BT1.2, BT2.2, C1.1, D1.1 (K), D2.1 (K), D3.1 (K), D4.1 (K), D5.1 (K), D6.1 (K), D7.1 (K), D8.1 (K), Q1.1 (E), Q2.1 (E), Q3.1 (E), Q4.1 (E), Q5.1 (E), R1.2, R2.2, R26.1, SW2.1, U1.8 (GND), U1.13 (~OE), U2.1 (GND)
unnamed: BT1.1, BT2.1, SW3.1
unnamed: C1.2, R28.2, U2.2 (TRIG), U2.6 (THRESH)
unnamed: D1.2 (A), R13.1
unnamed: D2.2 (A), R14.1
unnamed: D3.2 (A), R15.1
unnamed: D4.2 (A), R16.1
unnamed: D5.2 (A), R17.1
unnamed: D6.2 (A), R18.1
unnamed: D7.2 (A), R19.1
unnamed: D8.2 (A), R20.1
unnamed: Q1.2 (B), R3.1
unnamed: Q1.3 (C), R7.1, R10.2
unnamed: Q2.2 (B), R4.1
unnamed: Q2.3 (C), R8.1, R11.2
unnamed: Q3.2 (B), R5.1, R6.1
unnamed: Q3.3 (C), R9.1, R22.2
unnamed: Q4.2 (B), R10.1, R11.1
unnamed: Q4.3 (C), R12.1, R21.2
unnamed: Q5.2 (B), R21.1, R22.1
unnamed: R24.1, SW1.1
unnamed: R25.2, U1.16 (VCC)
unnamed: R27.2, R29.1, U2.8 (VCC)
unnamed: R28.1, R29.2, U2.7 (DIS_CH)
VCC: R7.2, R8.2, R9.2, R12.2, R23.2, R24.2, R25.1, R27.1, SW3.2, U1.10 (~SRCLR), U2.4 (~RESET)

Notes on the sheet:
Master Schematic - Christmas Bauble

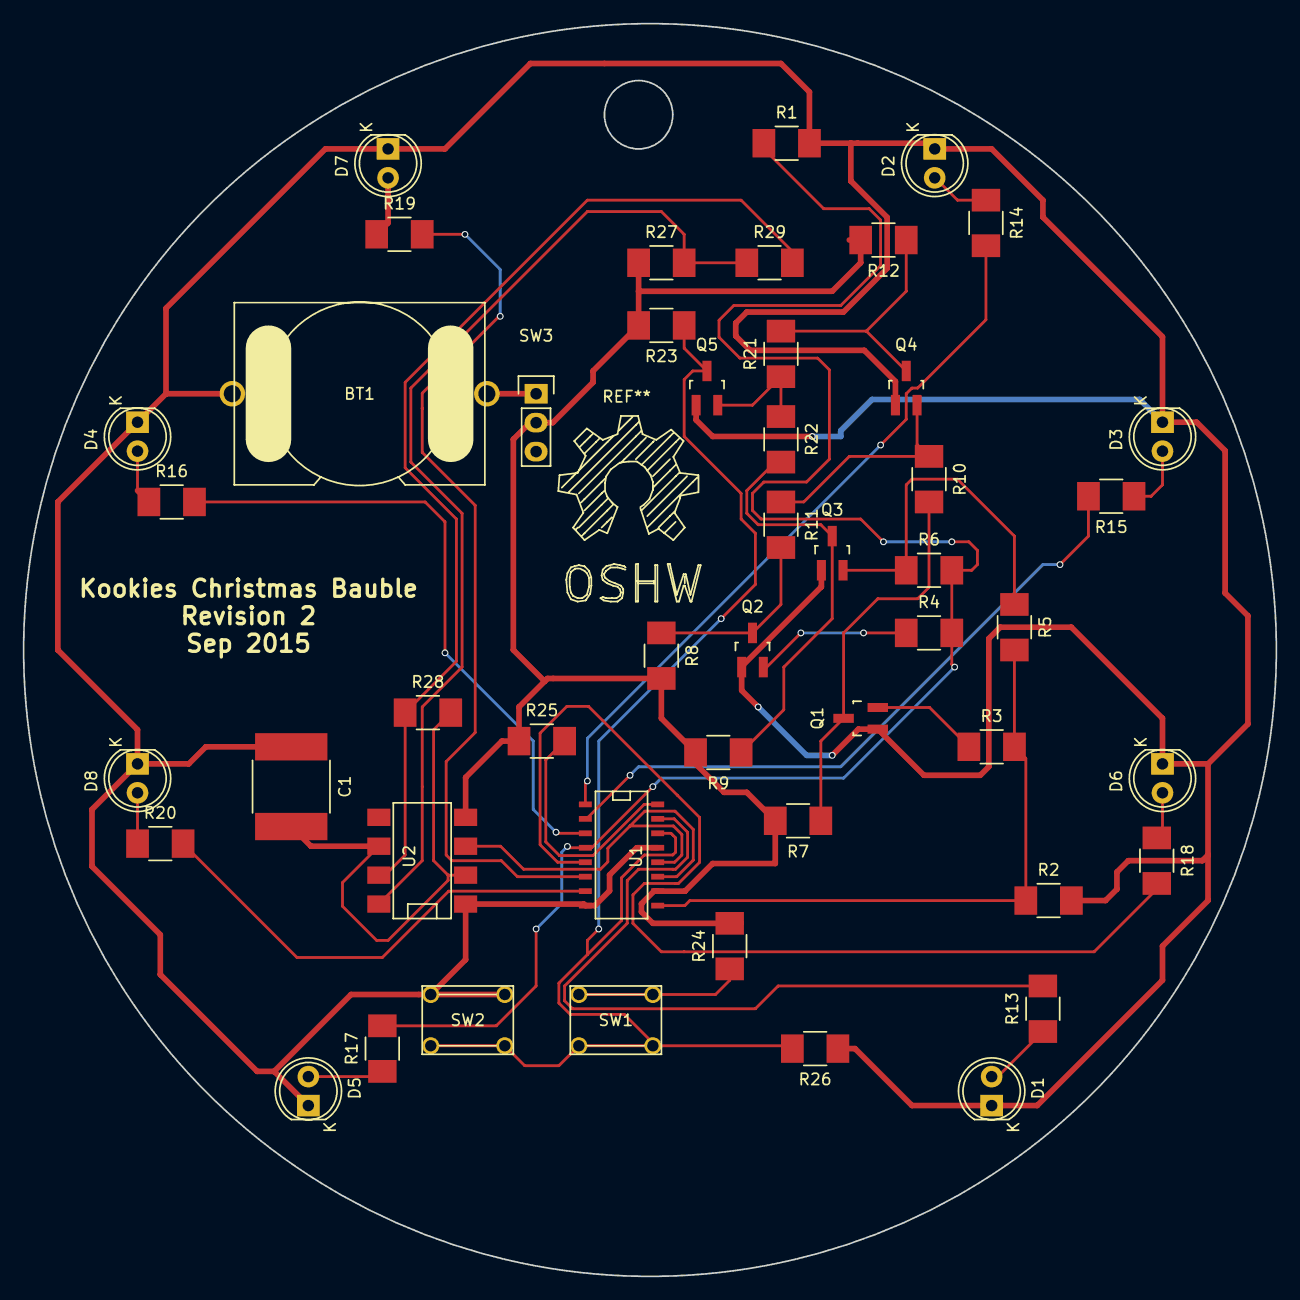
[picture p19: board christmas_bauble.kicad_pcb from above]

Board: 2 copper layers, 110.0 x 110.0 mm, 49 parts (0 on the bottom side), 36 nets.

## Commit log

2015-09-12 Adding first and second revision schematics and pcb.
    [christmas_bauble.kicad_pcb, christmas_bauble.sch, christmas_bauble_rev1.kicad_pcb]
2015-09-12 Updating stuff
    [christmas_bauble.kicad_pcb, christmas_bauble.sch]
2015-09-13 Finishing Revision 3 PCB which uses a single SMD XOR gate instead of one built from NPN transistors which greatly riduces the amount of traces required. Now only using one layer!
    [christmas_bauble.sch, christmas_bauble_rev2.kicad_pcb, christmas_bauble_rev3.kicad_pcb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]
2015-11-13 Some minor changes. This is the version that went into production. Woop woop \o/
    [christmas_bauble.kicad_pcb, christmas_bauble.sch, christmas_bauble_rev1.kicad_pcb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]
2015-11-17 Changing batteries on the board to 2 20mm coin cell batteries in paralell for longer lifetime. Routing batteries on the back via SMD holders.
    [christmas_bauble.sch, christmas_bauble_rev3.kicad_pcb, christmas_bauble_rev3.sch]
2015-11-26 Adding new picture and cleaning up repo. Old revisions are now archived.
    [christmas_bauble.kicad_pcb, christmas_bauble.sch, christmas_bauble_rev1.kicad_pcb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]
2016-01-01 Adding skeleton for revision 4 bauble...
    [_saved_christmas_bauble_rev4.sch, christmas_bauble_rev3-2.kicad_pcb, christmas_bauble_rev3.kicad_pcb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]
2016-01-05 Adding dip switches to the layout to program the bauble
    [_saved_christmas_bauble_rev4.sch, christmas_bauble_rev4.sch]
2016-01-05 Adding more debugging LEDs and a switch for 'Programmer mode'
    [christmas_bauble_rev4.sch]
2016-03-20 Updating some revision 4 files.
    [christmas_bauble_rev4.sch]
